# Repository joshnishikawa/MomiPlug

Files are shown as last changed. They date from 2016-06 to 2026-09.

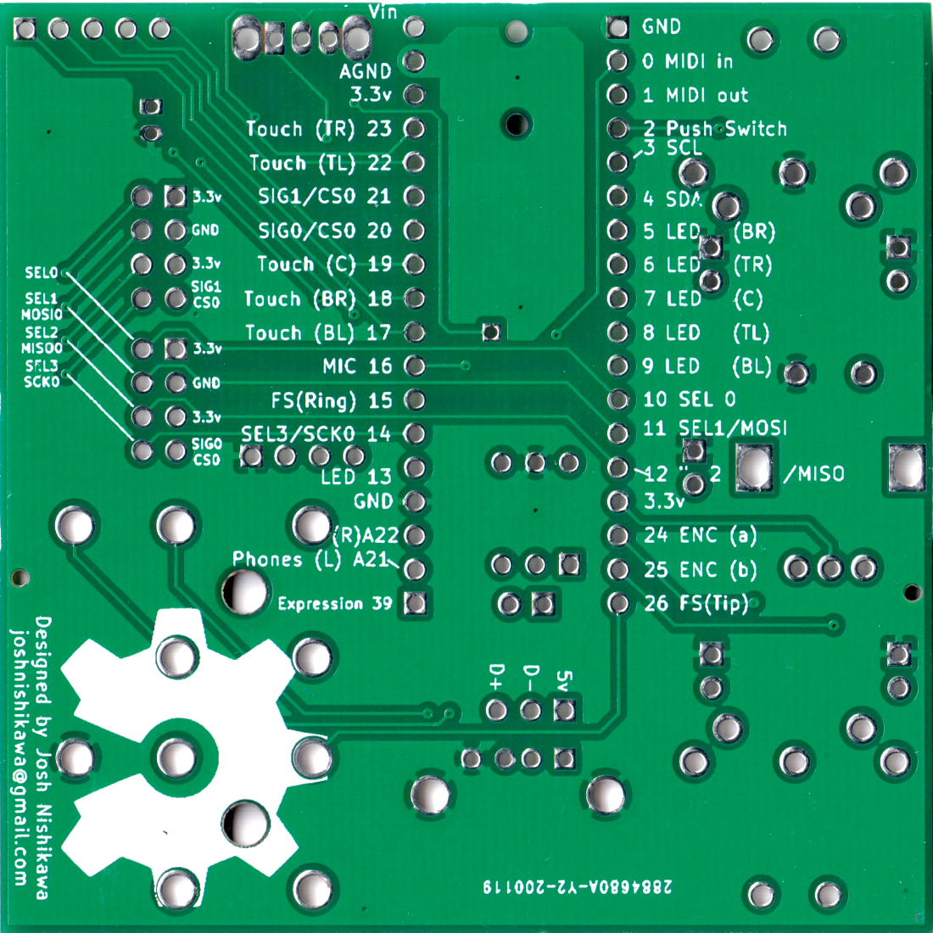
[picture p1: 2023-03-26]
MOMI3_silkscreen.jpg

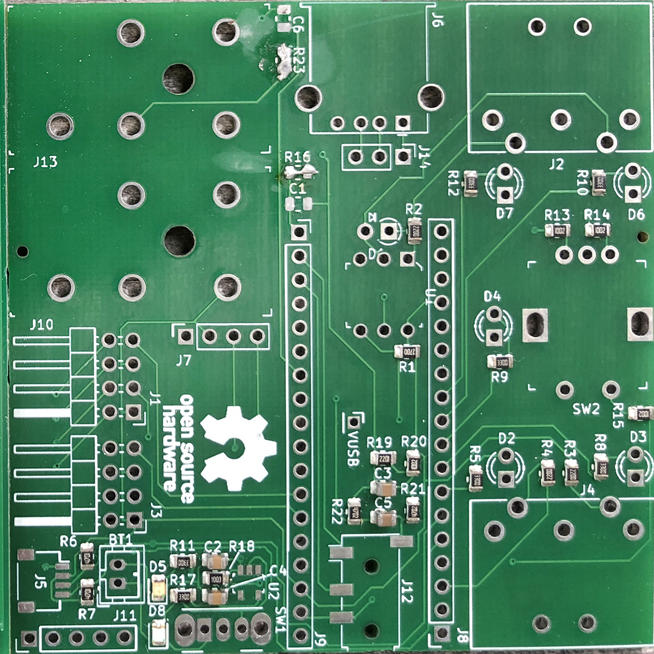
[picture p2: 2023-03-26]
MOMI3_surface.jpg

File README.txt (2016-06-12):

TEENSY 3.1 PIN ASSIGNMENTS
             ______
        ____|      |____
  GND -|-GND|      | 5V |- VBUS on USB host module
 MIDI -| 0  |______AGND-|- AGND (sleve and Mux16 GND)
 FS 1 -| 1        _3.3v-|- Voltage
SEL_A  |-2   AREF(_) 23 |- 1/4" analog return (ring)
SEL_B  |-3    A-1(_) 22-|  SER (display)
SEL_C  |-4    A-2(_) 21-|  Encoder Pin B
SEL_D  |-5           20-|  Encoder Pin A
 FS 0  |-6           19-| 'Edit' Button
 SRCK -| 7           18 |- Button 4
 RCLK -| 8           17 |- Button 3
  INT -| 9           16 |- Button 2
   SS  |-10          15 |- Button 1
 MOSI  |-11          14 |- Button 0
 MISO  |-12          13 |- SCK
       |________________|

  * '-' indicates which direction the wires run.

74HC595 (x2) PIN ASSIGNMENTS
             __ __
 Butn4 LED -| (_) |- 5V
 Butn3 LED -|     |- Butn5 LED
 Butn2 LED -|     |- SER from Teensy
 G Segment -|     |-
 F Segment -|  #1 |- RCLK
 E Segment -|     |- SRCK
 D Segment -|     |- 5V
       GND -|_____|- SER to #2
             __ __
 B Segment -| (_) |- 5V
 A Segment -|     |- C Segment
DP Segment -|     |- SER from #1
 Cathode 1 -|     |-
 Cathode 2 -|  #2 |- RCLK
 Cathode 3 -|     |- SRCK
 Butn1 LED -|     |- 5V
       GND -|_____|-

 * The 7 segments are split between
   the 2 chips so that a maximum of
   5 pins are HIGH at any given time.

7-SEGMENT LED PIN ASSIGNMENTS

      G  F  DP A  B
 _____|__|__|__|__|_
|O ___ O ___ O ___  |
| |   | |   | |   | |
| |___| |___| |___| |
| |   | |   | |   | |
| |___| |___| |___| |
|___________________|
   |  |  |  |  |  |
   E  1  2  C  D  3

 *It's wired up-side down so
  ignore the datasheet.

USB HOST MODULE PIN ASSIGNMENTS (from circuits@home)
          __________
         |          |
         |          |
       __|          |__
      |  |          |  |
      |  |__________|  |
      | _    5V -(_) _ |- (Be sure to break the VBUS jumper.)
  SS -|(_)          (_)|
MOSI -|(_)          (_)|
MISO -|(_)          (_)|
 SCK -|(_)          (_)|
      |(_)          (_)|
      |(_)          (_)|
      |(_)          (_)|
      |(_)          (_)|
3.3V -|(_)          (_)|- GND
      |(_)          (_)|- 3.3V
 GND -|(_)          (_)|
      |(_)          (_)|
      |________________|

5-PIN MIDI IN DIN PIN ASSIGNMENTS
_______________________
                       \
________________________\
      _____________      |
     /_____________\     |     ______________
    //      _2     \\    |    /     2    \   \__
   // 4_   (_)   _5 \\   |   / 5   0===  4\   \ \___
  ||  (_)       (_)  ||  |  |  0===     0==|        \
  ||  _           _  ||  |  |              |         |__
  || (_)         (_) ||  |  | 0===       0=|         |_ \
  || 1             3 ||  |  | 3          1 |         | \ \
  ||                 ||  |  |              |     ___/   \ \
   \\       _       //   |   \      _     /   /_/       / /
    \\_____| |_____//    |    \____| |___/___/         / /
     \-------------/     |                            / / 
_________________________|                            \ \

Pin 1 - Not Connected
Pin 2 - Not Connected
Pin 3 - Not Connected
Pin 4 - Through a 220 Ohm resistor and into 6N138 Pin 2
Pin 5 - From 6N138 Pin 3 

 * A diode and 270 Ohm resistor are also needed.
   See schematic below.

MIDI IN SCHEMATIC (6N138)        3.3V
                                  |
                           __ __  |   270 Ohm
            220 Ohm      -|1(_)8|~'~~~\/\/\/\_
DIN Pin 4~~~\/\/\/\~~~_~~~|2   7|-            |
DIN Pin 5~~~~~~~~~~~~~^~~~|3   6|~~~~~~~~~~~~~'~~~MIDI
                      D  -|4___5|~~GND          (Teensy)
                      i
                      o
                      d
                      e

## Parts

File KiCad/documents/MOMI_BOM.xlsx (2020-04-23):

Comment | Designator | Footprint | LCSC Part #（optional）
10uF | C1,C3,C5,C6 | C_0805_2012Metric
1uF | C2,C4 | C_0805_2012Metric
Green LED | D5 | LED_0805_2012Metric
Red LED | D8 | LED_0805_2012Metric
270 | R1 | R_0805_2012Metric
220 | R2,R3,R4 | R_0805_2012Metric
330 | R5,R8,R9,R10,R12,R11,R17 | R_0805_2012Metric
4.7k | R6,R7 | R_0805_2012Metric
10k | R13,R14,R15,R20 | R_0805_2012Metric
47k | R16,R21,R22,R23 | R_0805_2012Metric
2.2k | R19 | R_0805_2012Metric
100k | R18 | R_0805_2012Metric

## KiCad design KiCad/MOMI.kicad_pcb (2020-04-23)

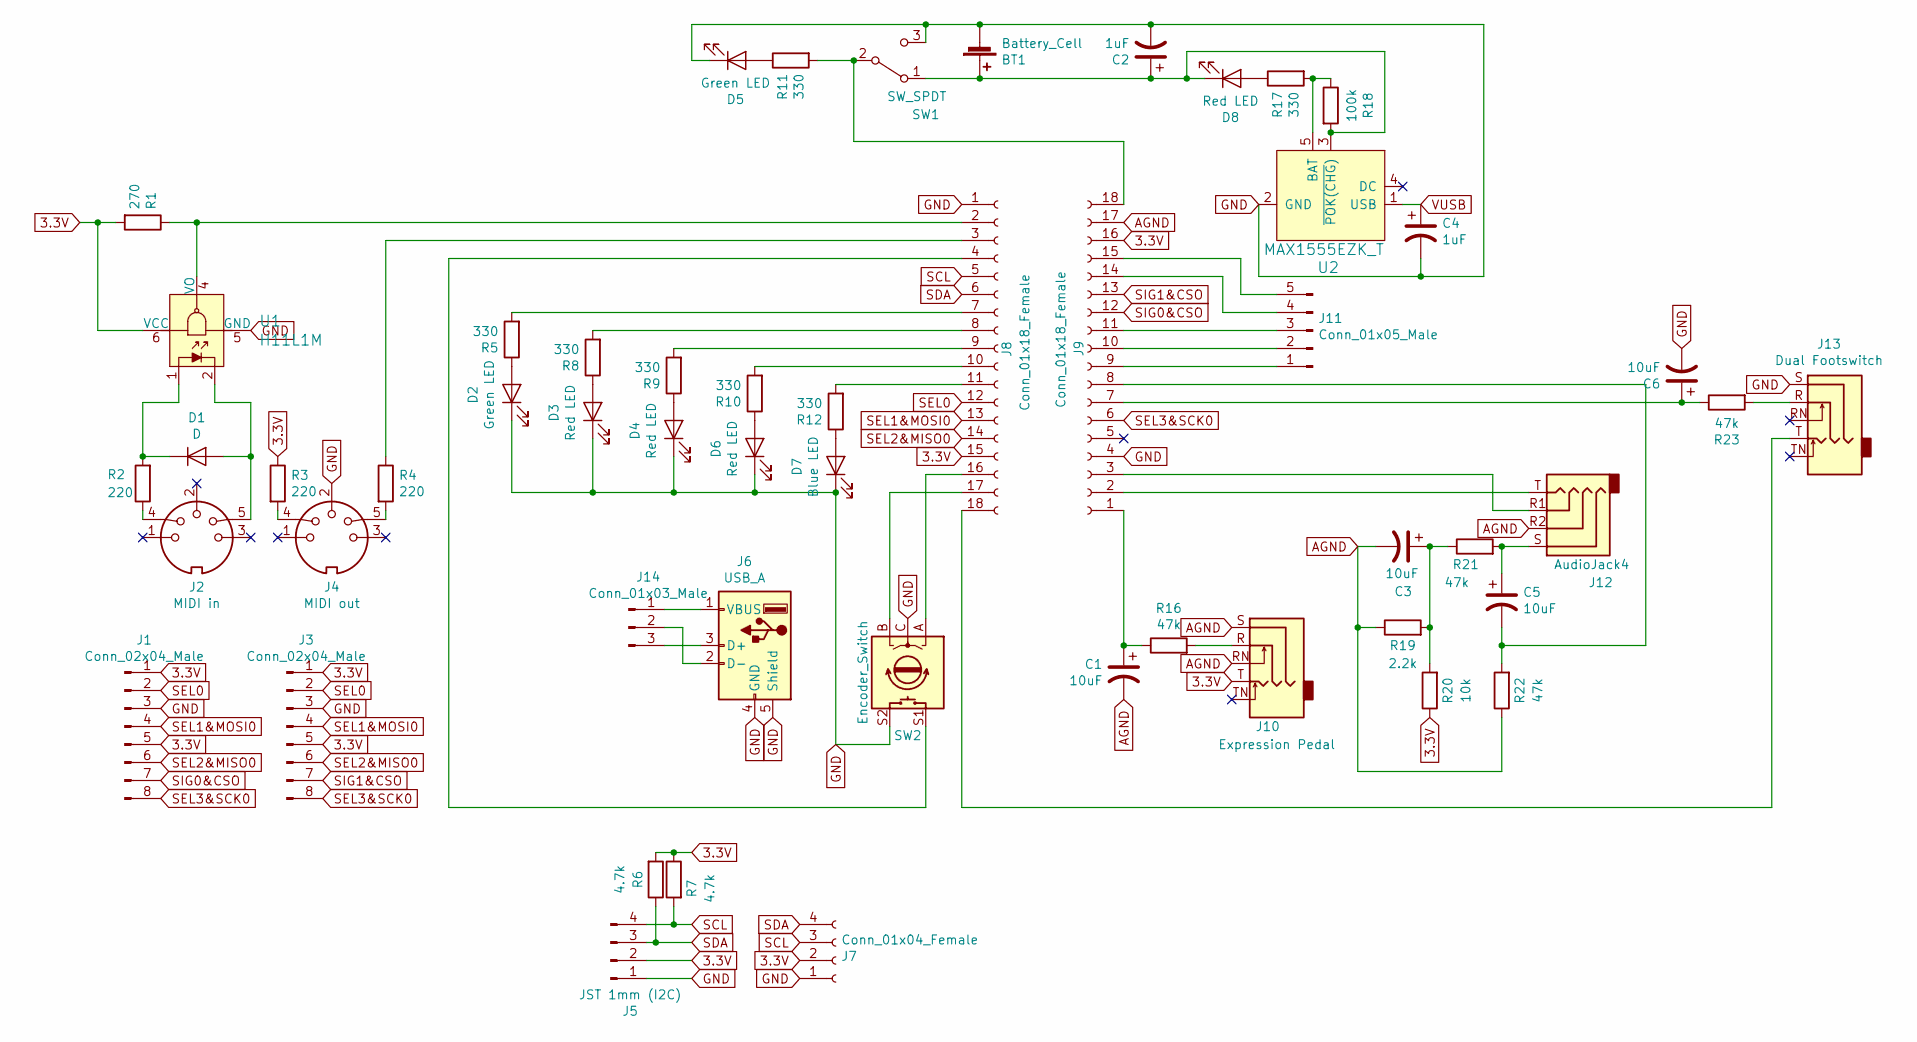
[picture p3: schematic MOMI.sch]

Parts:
BT1: Battery_Cell; JST_PH_B2B-PH-K_1x02_P2.00mm_Vertical
C1, C3, C5, C6: 10uF; C_0805_2012Metric
C2, C4: 1uF; C_0805_2012Metric
D1: D; D_A-405_P2.54mm_Vertical_AnodeUp
D2: Green LED; LED_D3.0mm
D3, D4, D6: Red LED; LED_D3.0mm
D5: Green LED; LED_0805_2012Metric
D7: Blue LED; LED_D3.0mm
D8: Red LED; LED_0805_2012Metric
J1, J3: Conn_02x04_Male; PinHeader_2x04_P2.54mm_Horizontal
J2: MIDI in; SDS-50J
J4: MIDI out; SDS-50J
J5: JST 1mm (I2C); JST_SH_SM04B-SRSS-TB_1x04-1MP_P1.00mm_Horizontal
J6: USB_A; USB_A_Stewart_SS-52100-001_Horizontal
J7: Conn_01x04_Female; PinSocket_1x04_P2.54mm_Vertical
J8, J9: Conn_01x18_Female; PinSocket_1x18_P2.54mm_Vertical
J10: Expression Pedal; Headphone_Jack_6.35mm_RA49B14B
J11: Conn_01x05_Male; PinHeader_1x05_P2.54mm_Vertical
J12: AudioJack4; Jack_3.5mm_PJ320D_Horizontal
J13: Dual Footswitch; Headphone_Jack_6.35mm_RA49B14B
J14: Conn_01x03_Male; Pin_Header_Straight_1x03_Pitch2.54mm
R1: 270; R_0805_2012Metric
R2, R3, R4: 220; R_0805_2012Metric
R5, R8, R9, R10, R11, R12, R17: 330; R_0805_2012Metric
R6, R7: 4.7k; R_0805_2012Metric
R16, R21, R22, R23: 47k; R_0805_2012Metric
R18: 100k; R_0805_2012Metric
R19: 2.2k; R_0805_2012Metric
R20: 10k; R_0805_2012Metric
SW1: SW_SPDT; SW_CuK_OS102011MA1QN1_SPDT_Angled
SW2: Encoder_Switch; Rotary_Encoder_Switched_PEC11R
U1: H11L1M; DIP-6_W7.62mm; MPN H11L1M; Digi-Key_PN H11L1-MQT-ND
U2: MAX1555EZK_T; SOT-753; MPN MAX1555EZK+T; Digi-Key_PN MAX1555EZK+TCT-ND

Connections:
3.3V: J1.1, J1.5, J3.1, J3.5, J5.2, J7.2, J8.15, J9.16, J10.T, R1.2, R3.1, R6.2, R7.1, R20.1, U1.6 (VCC)
AGND: C1.2, C3.2, J9.17, J10.RN, J10.S, J12.R2, R19.1, R22.1
GND: BT1.2 (-), C2.2, C4.2, C6.2, D2.1 (K), D3.1 (K), D4.1 (K), D5.1 (K), D6.1 (K), D7.1 (K), J1.3, J3.3, J4.2, J5.1, J6.4 (GND), J6.5 (Shield), J7.1, J8.1, J9.4, J13.S, SW1.3 (C), SW2.C, SW2.S2, U1.5 (GND), U2.2 (GND)
unnamed: BT1.1 (+), C2.1, D8.1 (K), R18.2, SW1.1 (A), U2.3 (~POK(CHG))
unnamed: C1.1, J9.1, R16.1
unnamed: C3.1, R19.2, R20.2, R21.1
unnamed: C5.1, J12.S, R21.2
unnamed: C5.2, J9.8, R22.2
unnamed: C6.1, J9.7, R23.1
unnamed: D1.1 (K), R2.2, U1.1
unnamed: D1.2 (A), J2.5, U1.2
unnamed: D2.2 (A), R5.1
unnamed: D3.2 (A), R8.1
unnamed: D4.2 (A), R9.1
unnamed: D5.2 (A), R11.1
unnamed: D6.2 (A), R10.1
unnamed: D7.2 (A), R12.1
unnamed: D8.2 (A), R17.1
unnamed: J2.4, R2.1
unnamed: J4.4, R3.2
unnamed: J4.5, R4.2
unnamed: J8.2, R1.1, U1.4 (VO)
unnamed: J8.3, R4.1
unnamed: J8.4, SW2.S1
unnamed: J8.7, R5.2
unnamed: J8.8, R8.2
unnamed: J8.9, R9.2
unnamed: J8.10, R10.2
unnamed: J8.11, R12.2
unnamed: J8.16, SW2.A
unnamed: J8.17, SW2.B
unnamed: J9.18, R11.2, SW1.2 (B)
unnamed: J10.R, R16.2
unnamed: J9.9, J11.1
unnamed: J9.10, J11.2
unnamed: J9.11, J11.3
unnamed: J9.14, J11.4
unnamed: J9.15, J11.5
unnamed: J9.3, J12.R1
unnamed: J9.2, J12.T
unnamed: J13.R, R23.2
unnamed: J8.18, J13.T
unnamed: J6.1 (VBUS), J14.1
unnamed: J6.2 (D-), J14.2
unnamed: J6.3 (D+), J14.3
unnamed: R17.2, R18.1, U2.5 (BAT)
SCL: J5.4, J7.3, J8.5, R7.2
SDA: J5.3, J7.4, J8.6, R6.1
SEL0: J1.2, J3.2, J8.12
SEL1&MOSI0: J1.4, J3.4, J8.13
SEL2&MISO0: J1.6, J3.6, J8.14
SEL3&SCK0: J1.8, J3.8, J9.6
SIG0&CSO: J1.7, J9.12
SIG1&CSO: J3.7, J9.13
VUSB: C4.1, U2.1 (USB)

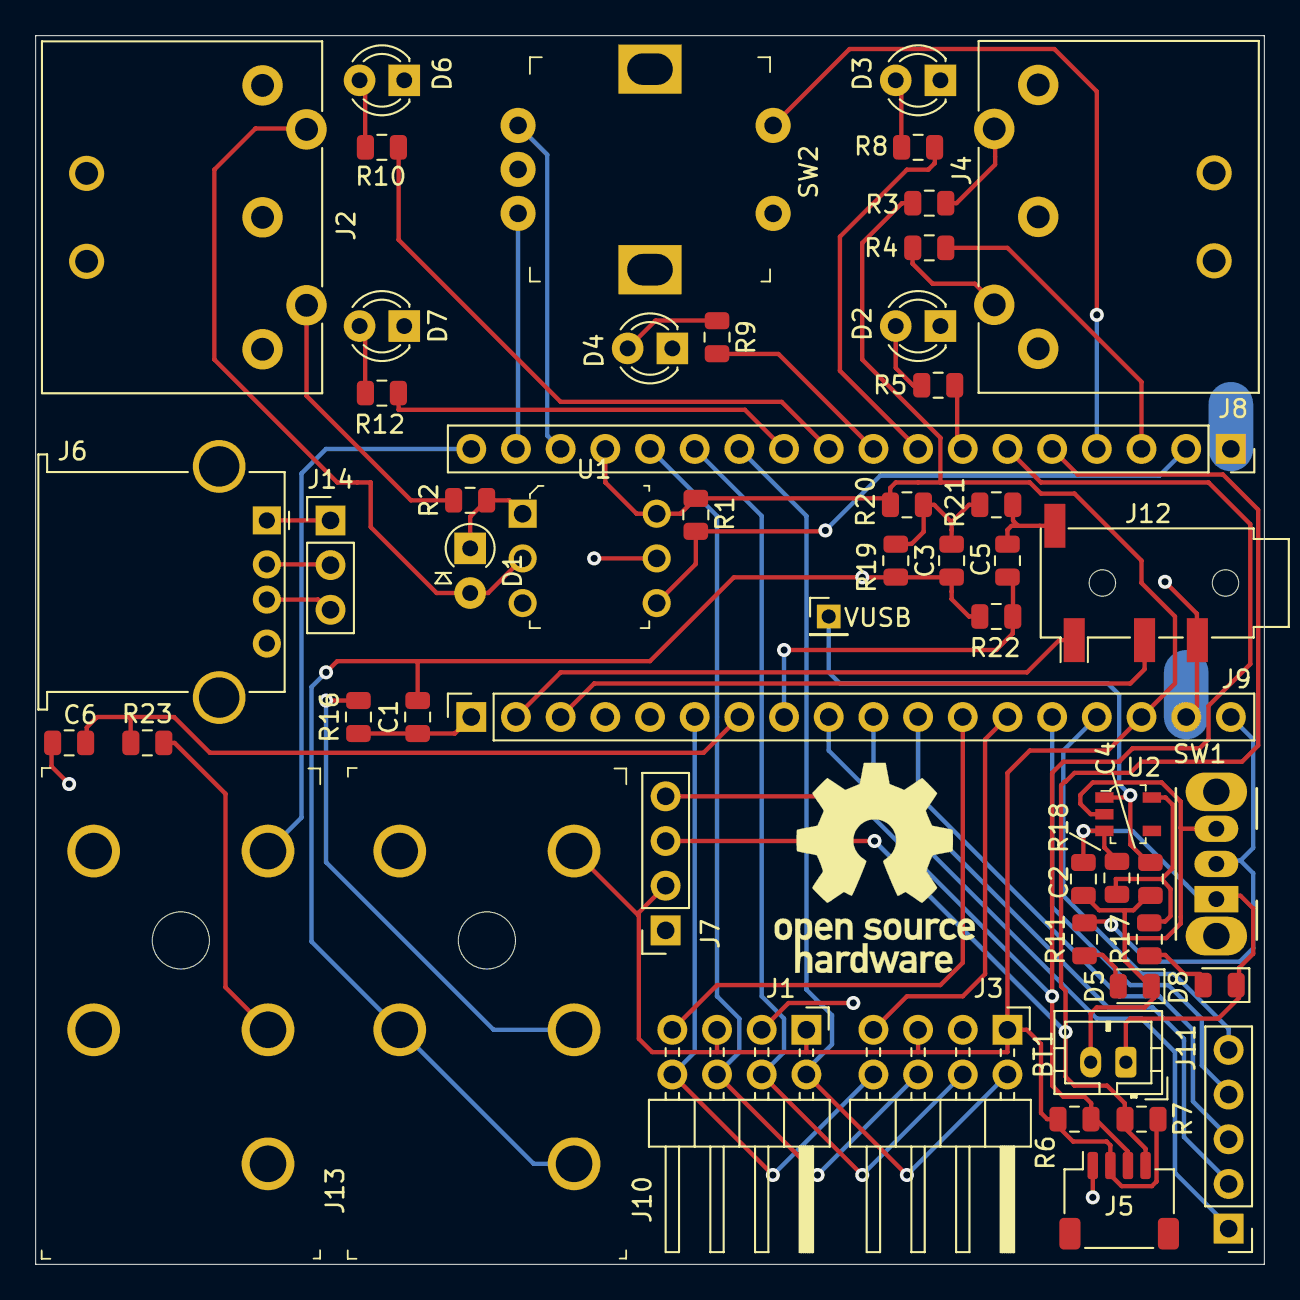
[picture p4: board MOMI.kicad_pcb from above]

Board: 2 copper layers, 69.8 x 69.8 mm, 53 parts (0 on the bottom side), 55 nets.

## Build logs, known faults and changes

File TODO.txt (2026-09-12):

MOMI should start in CONTROL mode.

If any of the touch, footswitch or MIDIpot inputs is triggered while the EDIT button is being held, 
the EDIT button may be released and we remain in CONFIG mode to allow the encoder to set values for the last item triggered.
When the EDIT button is pressed and released again, these values are set and we return to the previously
selected mode (TRACK or CONTROL).

If the Bottom Right touch input is selected (pin 17), all reads on pins 20 and 21 are halted.
THIS IS TOP PRIORITY! WE MUST BE ABLE TO STOP MUXES FROM BEING READ!
The current read state of the MUX pins is displayed on the 7-segment display. The EDIT button
may be released and the encoder may be used to scroll through these options.
  '----' Both MUX pins will be ignored.
  'A---' Pin 20 will read a single MIDIpot.
  'A--A' Pins 20 and 21 will each read a single MIDIpot.
  '8---' Pin 20 will read MUX8.
  '8--A' Pin 20 will read MUX8 and pin 21 swill read a single MIDIpot.
  '8--8' Pins 20 and 21 will each read a MUX8.
  'SPI-' Use SPI only - MOSI on pin 11, MISO on pin 12, CS on pin 20 and SCK on pin 14 ( use SPI.setSCK(14) )
  'SPIA' Use SPI on pin 20 and a single MIDIpot on pin 21.

If the Top Right input is selected (pin 23), the current octave setting is display on the 7-segment display.
The EDIT button may be released and the encoder may be used to scroll through these options. 
  'ocL-' Each note will be accompanied by a second note an octave lower.
  'oc-H' Each note will be accompanied by a second note an octave higher.
  'ocLH' Each note will be accompanied by two additional notes, one an octave higher and one an octave lower.
  'oc--' Only the note played will be sent.

If the Top Left input is selected (pin 19), the current transpose setting is displayed on the 7-segment display.
The EDIT button may be released and the encoder may be used to scroll down to -12 or up to 12 for note transposition.

If the Bottom Left input is elected (pin 18), the current expression state is displayed on the 7-segment display.
The EDIT button may be released and the encoder may be used to scroll through these options.
  'CAOS' Currently incorrectly implemented (check the 'MOMI3 init' commit).
  'ECHO' A digital delay where, the higher the reading, the more repeats and longer decay time.
  'both' Both CAOS and ECHO are used
  '----' Neither are used.

If the Center input is selected (pin 22), toggles whether MIDI FX apply to usb host too (wet, dry).

If any MIDIpot input is triggered while the EDIT button is held down,
the cut / -cut functionality should be the same but turning the encoder should change the CC number.
When EDIT is released 'SEnS' should be displayed on the 7-segment and, if the analog read changes
by more than 100, we need to keep track of inHi and inLo (displaying the analog value on th 7-segment). 
When the EDIT button is pressed and released again, inHi should be set to the 
highest reading -10 and inLo should be set to the lowest reading +10.

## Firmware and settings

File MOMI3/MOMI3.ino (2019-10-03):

#include "MOMIPLUG.h"

MIDI_CREATE_DEFAULT_INSTANCE();
MIDI_CREATE_INSTANCE(HardwareSerial, Serial1, MIDI1);
MIDI_CREATE_INSTANCE(HardwareSerial, Serial1, MIDI2);
MIDI_CREATE_INSTANCE(HardwareSerial, Serial1, MIDI3);
USBHost teensyUSBHost;
USBHub hub1(teensyUSBHost);
USBHub hub2(teensyUSBHost);
MIDIDevice USBMIDI(teensyUSBHost);

// PIN ASSIGNMENTS ##################################################
//MIDI in  is pin 0 by default
//MIDI out is pin 1 by default
const int enableFS = 2; //enable footswitches
const int enableEXP = 3;//enable expression pedal
const int sel_a = 4;    //selectors for analog and digital mux inputs
const int sel_b = 55;   //55 because pin 5 got fried. Oops!
const int sel_c = 6;    //
const int sel_d = 7;    //
const int led3 = 8;     //LED on center right
const int fs1led = 9;   //LED for FS1
const int led2 = 10;    //LED on upper right
const int fs0led = 11;  //LED for FS0
const int editPin = 12; //edit button (push switch on encoder)
const int led0 = 13;    //the onboard (orange) LED
const int expPin = 14;  //analog input for expression pedal
const int ringPin = 15; //footswitch 1
const int tipPin = 16;  //footswitch 0
const int but1pin = 17; //onboard buttons
const int but2pin = 18; //
const int but3pin = 19; //
const int muxPin1 = 20; //muxed analog input
const int audioVol = 21;//volume for 3.5mm jack
const int cap0pin = 22; //onboard Capacitive touch sensor
const int muxPin0 = 23; //muxed digital input
const int encPinA = 24; //pin A of encoder
const int encPinB = 25; //pin B of encoder
const int led1 = 26;    //LED on upper left

const int segG = 27;    //Pin 7
const int segD = 28;    //Pin 8
const int segF = 29;    //Pin 9
const int digit2 = 30;  //Pin 10
const int segB = 31;    //Pin 11
const int segA = 32;    //Pin 12
const int digit1 = 33;  //Pin 1
const int segE = 34;    //Pin 2
const int segC = 35;    //Pin 3
const int digit3 = 36;  //Pin 4
const int segDP= 37;    //Pin 5
const int digit4 = 38;  //Pin 6

const int analog = 39;  //2-pin female header for variable resistors
const int audioR = A21; //right headphone
const int audioL = A22; //left headphone

// DECLARATOINS #########################################################
byte MIDIchannel = 3;
bool readMIDIthru = true;
bool readAnalogMUX = false;
bool readDigitalMUX = false;
bool trackMode = false;
SevSeg DSP;
char DSPstring[5] = "    ";
int DP = 0;
Editor editor = Editor(encPinA, encPinB, editPin);
Track* Ts[3];
MIDIbutton* Bs[23];
MIDIpot* Ps[18];

// INITIALIZATION #######################################################
void setup(){
  Serial.begin(115200); //is this really necessary?
  delay(1500);
  MIDIchannel = EEPROM.read(0);
  readMIDIthru = EEPROM.read(1);
  readAnalogMUX = EEPROM.read(2);
  readDigitalMUX = EEPROM.read(3);
  DSP.Begin(COMMON_CATHODE, 4, digit1, digit2, digit3, digit4,
                               segA, segB, segC, segD, segE, segF, segG, segDP);
  DSP.SetBrightness(100); //Set the display to 100% brightness level
  
  Ts[0] = new Track(but1pin, 105, 2100);
  Ts[1] = new Track(but2pin, 106, 2100);
  Ts[2] = new Track(but3pin, 107, 2100);

  Bs[0] = new MIDIbutton(but1pin,  102, 1, 2100);
  Bs[1] = new MIDIbutton(but2pin,  103, 1, 2100);
  Bs[2] = new MIDIbutton(but3pin,  104, 1, 2100);
  Bs[3] = new MIDIbutton(ringPin,  80, EEPROM.read(4));
  Bs[4] = new MIDIbutton(tipPin,  81, EEPROM.read(8));
  Bs[5] = new MIDIbutton(ringPin, 107, 0);
  Bs[6] = new MIDIbutton(tipPin, 107, 0); //DELETE ME MAYBE???
  for(int i=7; i<23; i++){Bs[i] = new MIDIbutton(muxPin0,9+i, 1);} // CC 16~31

  Ps[0] = new MIDIpot(expPin, 85, EEPROM.read(12));
  Ps[0]->inputRange(8, 1015); // just cuz my expression pedal ain't great 
  Ps[1] = new MIDIpot(analog, 14);
  EEPROM.get(16, Ps[1]->inLo);
  EEPROM.get(20, Ps[1]->inHi);
  EEPROM.get(24, editor.touchLo);
  EEPROM.get(28, editor.touchHi);
  for(int i=2; i<18; i++){Ps[i] = new MIDIpot(muxPin1,14+i);} // CC 16~31

  pinMode(sel_a, OUTPUT);             //analog and digital mux selector 1
  pinMode(sel_b, OUTPUT);             //analog and digital mux selector 2
  pinMode(sel_c, OUTPUT);             //analog and digital mux selector 3
  pinMode(sel_d, OUTPUT);             //analog and digital mux selector 4
  pinMode(enableFS, INPUT_PULLUP);
  pinMode(enableEXP, INPUT_PULLUP);
  pinMode(fs0led, OUTPUT);
  pinMode(fs1led, OUTPUT);
  pinMode(led0, OUTPUT);
  pinMode(led1, OUTPUT);
  pinMode(led2, OUTPUT);
  pinMode(led3, OUTPUT);

  MIDI1.begin(MIDI_CHANNEL_OMNI); //MIDI1 MIDI2 and MIDI3 only need to send
  MIDI2.begin(MIDI_CHANNEL_OMNI); //no need to read each one
  MIDI3.begin(MIDI_CHANNEL_OMNI); //or set handlers for incoming messages

  MIDI.begin(MIDI_CHANNEL_OMNI);
  MIDI.setHandleNoteOff(onNoteOff);
  MIDI.setHandleNoteOn(onNoteOn);
  MIDI.setHandleAfterTouchPoly(onPolyPressure);
  MIDI.setHandleControlChange(onControl);
  MIDI.setHandleProgramChange(onProgram);
  MIDI.setHandleAfterTouchChannel(onAfterTouch);
  MIDI.setHandlePitchBend(onPitchBend);

  teensyUSBHost.begin();
  USBMIDI.setHandleNoteOff(onUSBNoteOff);
  USBMIDI.setHandleNoteOn(onUSBNoteOn);
  USBMIDI.setHandleAfterTouchPoly(onUSBPolyPressure);
  USBMIDI.setHandleControlChange(onUSBControl);
  USBMIDI.setHandleProgramChange(onUSBProgram);
  USBMIDI.setHandleAfterTouchChannel(onUSBAfterTouch);
  USBMIDI.setHandlePitchChange(onUSBPitchBend);

  // UNCOMMENT THESE TO RESTORE DEFAULTS
  /*EEPROM.put(0, 3); EEPROM.put(1, true);
  EEPROM.put(2, false); EEPROM.put(3, false);
  EEPROM.put(4, 0); EEPROM.put(8, 1);
  EEPROM.put(12, 0); EEPROM.put(16, 0); EEPROM.put(20, 1023);*/
}

// PROGRAM ##############################################################
void loop(){
  editor.bounce->update();

  // On Button Release ##################################################
  if (editor.bounce->risingEdge()){
    strcpy(DSPstring, "    ");
    editor.encoder->write(0);
    if (editor.editing == true){
      if(editor.target == 0){EEPROM.put(0, MIDIchannel);}
      else if(editor.target == 1){EEPROM.put(1, readMIDIthru);}
      else if(editor.target == 2){EEPROM.put(2, readAnalogMUX);}
      else if(editor.target == 3){EEPROM.put(3, readDigitalMUX);}
      else if(editor.target == 4){EEPROM.put(4, Bs[3]->mode);}
      else if(editor.target == 8){EEPROM.put(8, Bs[4]->mode);}
      else if(editor.target == 12){EEPROM.put(12, Ps[0]->mode);}
      else if(editor.target == 16){
        Ps[1]->inLo = editor.newInLo;
        Ps[1]->inHi = editor.newInHi;
        EEPROM.put(16, Ps[1]->inLo);
        EEPROM.put(20, Ps[1]->inHi);
      }
      else if(editor.target == 24){
        EEPROM.put(24, editor.touchLo);
        EEPROM.put(28, editor.touchHi);
      }
      editor.editing = false;
    }
    else{
      trackMode = !trackMode;
      if(trackMode){strcpy(DSPstring, "trac");}
      else{strcpy(DSPstring, "ctrl");}
    }
  }

  // On Button Press ####################################################
  else if (editor.bounce->fallingEdge()){ //calibrate the analog header
    editor.newInLo = analogRead(analog);
    editor.newInHi = editor.newInLo;
    editor.touchLo = touchRead(cap0pin);
    editor.touchHi = editor.touchLo;
    sprintf(DSPstring, "%4d", MIDIchannel);
  }

  // On Hold ############################################################
  // TODO: 'editing' and 'target' could be reduced to 1 variable inside the sketch
  else if (editor.bounce->read() == LOW){
    int newChannel = editor.editChannel();
    if (newChannel != MIDIchannel){
      editor.editing = true;
      editor.target = 0;
      MIDIchannel = newChannel;
      sprintf(DSPstring, "%4d", MIDIchannel);
    }
    if (Bs[0]->read() == 127){
      editor.editing = true;
      editor.target = 1;
      readMIDIthru = !readMIDIthru;
    }
    if (Bs[1]->read() == 127){
      editor.editing = true;
      editor.target = 2;
      readAnalogMUX = !readAnalogMUX;
    }
    if (Bs[2]->read() == 127){
      editor.editing = true;
      editor.target = 3;
      readDigitalMUX = !readDigitalMUX;
    }
    if (digitalRead(enableFS)){ // TODO: use delay to prevent MIDI when hot-plugging
      if (Bs[3]->read() == 127){
        editor.editing = true;
        editor.target = 4;
        Bs[3]->mode = Bs[3]->mode == 1 ? 0 : 1;
        if(Bs[3]->mode == 1){strcpy(DSPstring, "lach");}
        else{strcpy(DSPstring, "hold");}
      }
      if (Bs[4]->read() == 127){
        editor.editing = true;
        editor.target = 8;
        Bs[4]->mode = Bs[4]->mode == 1 ? 0 : 1;
        if(Bs[4]->mode == 1){strcpy(DSPstring, "lach");}
        else{strcpy(DSPstring, "hold");}
      }
    }
    if (digitalRead(enableEXP) && Ps[0]->read() == 127){ // TODO: use delay to prevent MIDI when hot-plugging
      editor.editing = true;
      editor.target = 12;
      Ps[0]->mode = !Ps[0]->mode;
      if(Ps[0]->mode){strcpy(DSPstring, " cut");}
      else{strcpy(DSPstring, "-cut");}
    }
    
    if (editor.setAnalog(analog)){
      editor.editing = true;
      editor.target = 16;
      strcpy(DSPstring, "setH");
    }

    if (editor.setTouch(cap0pin)){
      editor.editing = true;
      editor.target = 24;
      strcpy(DSPstring, "setT");
    }

    digitalWrite(led1, readMIDIthru);
    digitalWrite(led2, readAnalogMUX);
    digitalWrite(led3, readDigitalMUX);
  }
  
  else{
  // In Track Mode Or Control Mode ######################################
    int newVal = 0;
    if (digitalRead(3) == HIGH){
      newVal = Ps[0]->send();              // Send MIDI for EXP Pedal
      if (newVal >= 0){
        sprintf(DSPstring, "%4d", newVal);      
        DSPstring[0] = 'E';
      }
    }
    newVal = Ps[1]->send();              // Send MIDI for Analog Header
    if (newVal >= 0){
      sprintf(DSPstring, "%4d", newVal);      
      DSPstring[0] = 'h';
    }

    if (readMIDIthru){
      teensyUSBHost.Task();
      USBMIDI.read();
      MIDI.read();
      digitalWrite(led0, chaos(cap0pin, editor.touchLo, editor.touchHi*.8, editor.touchHi, 24, 96) + 1);
      // adding 1 to the returned value of -1 makes 0 which turns the LED off, otherwise on
    }

    if (readAnalogMUX || readDigitalMUX){
    for(int i=0; i<8; i++){               // USE i<16 FOR MUX16
//        digitalWrite(sel_d, (i&15)>>3); // UNCOMMENT FOR MUX16
        digitalWrite(sel_c, (i&7)>>2);
        digitalWrite(sel_b, (i&3)>>1);
        digitalWrite(sel_a, (i&1));

        if (readAnalogMUX){
          newVal = Ps[i+2]->send();
          if (newVal >= 0){
            sprintf(DSPstring, "%4d", newVal);
            DSPstring[0] = 'A';
          }
        }
        if (readDigitalMUX){
          newVal = Bs[i+7]->send();
          if (newVal >= 0){
            sprintf(DSPstring, "%4d", newVal);
            DSPstring[0] = 'd';
          }
        }
      }
    }  
    // In Track Mode ######################################################
    if (trackMode){
      int incdec = editor.encoder->read();
      for(int i=0; i<3; i++){
        int newState = Ts[i]->send();
        if(newState >= 0){
          sprintf(DSPstring, "%4d", newState);
        }
        if (incdec){
          int newLevel = Ts[i]->vol(incdec);
          if(newLevel >= 0){
            sprintf(DSPstring, "%4d", newLevel);
          }
        }
      }
      if (incdec){editor.encoder->write(0);}
      bool recState = record(Bs[5]->read() == 127, Bs[6]->read() == 127);
      DP = 15;
      digitalWrite(fs0led, recState);
      digitalWrite(fs1led, !digitalRead(tipPin));
      digitalWrite(led1, Ts[0]->state);
      digitalWrite(led2, Ts[1]->state);
      digitalWrite(led3, Ts[2]->state);
    }

    // In Control Mode ####################################################
    else{
      newVal = editor.send();
      if(newVal >= 0){
        sprintf(DSPstring, "%4d", editor.level);
        DSPstring[0] = 'r';
      }
      for(int i=0;i<3;i++){                // Send MIDI for Onboard Buttons
        newVal = Bs[i]->send();
        if (newVal >= 0){
          sprintf(DSPstring, "%4d", newVal);
          DSPstring[0] = 'b';
        }
      }
      if (digitalRead(2) == HIGH){
        for(int i=3;i<5;i++){                // Send MIDI for Foot Switches
          newVal = Bs[i]->send();
          if (newVal >= 0){
            sprintf(DSPstring, "%4d", newVal);
            DSPstring[0] = 'f';
          }
        }
      }
      
      DP = 0;
      digitalWrite(led1, Bs[0]->state);
      digitalWrite(led2, Bs[1]->state);
      digitalWrite(led3, Bs[2]->state);
      digitalWrite(fs0led, Bs[3]->state);
      digitalWrite(fs1led, Bs[4]->state);
    }
  }
  DSP.DisplayString(DSPstring, DP); // Display most recently stored information
}

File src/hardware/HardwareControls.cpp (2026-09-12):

#include "HardwareControls.h"

HardwareControls hw;

HardwareControls::HardwareControls()
    : encoderButton(Pins::ENCODER_BUTTON, 50),
      encoder(Pins::ENCODER_A, Pins::ENCODER_B),
      encoderLevel(0),
      touchTopLeft(Pins::TOUCH_TOP_LEFT, MidiCC::TOUCH_TOP_LEFT, LATCH, TOUCH),
      touchCenter(Pins::TOUCH_CENTER, MidiCC::TOUCH_CENTER, LATCH, TOUCH),
      touchTopRight(Pins::TOUCH_TOP_RIGHT, MidiCC::TOUCH_TOP_RIGHT, LATCH, TOUCH),
      touchBottomRight(Pins::TOUCH_BOTTOM_RIGHT, MidiCC::TOUCH_BOTTOM_RIGHT, LATCH, TOUCH),
      footSwitch1(Pins::FOOTSWITCH_1, MidiCC::FOOTSWITCH_1, MOMENTARY),
      footSwitch0(Pins::FOOTSWITCH_0, MidiCC::FOOTSWITCH_0, LATCH),
      expressionPedal(Pins::EXPRESSION_PEDAL, MidiCC::EXPRESSION_PEDAL),
      mux0Pots{
          MIDIpot(Pins::MUX_ANALOG_IN_0, MidiCC::MUX0_POT_BASE + 0),
          MIDIpot(Pins::MUX_ANALOG_IN_0, MidiCC::MUX0_POT_BASE + 1),
          MIDIpot(Pins::MUX_ANALOG_IN_0, MidiCC::MUX0_POT_BASE + 2),
          MIDIpot(Pins::MUX_ANALOG_IN_0, MidiCC::MUX0_POT_BASE + 3),
          MIDIpot(Pins::MUX_ANALOG_IN_0, MidiCC::MUX0_POT_BASE + 4),
          MIDIpot(Pins::MUX_ANALOG_IN_0, MidiCC::MUX0_POT_BASE + 5),
          MIDIpot(Pins::MUX_ANALOG_IN_0, MidiCC::MUX0_POT_BASE + 6),
          MIDIpot(Pins::MUX_ANALOG_IN_0, MidiCC::MUX0_POT_BASE + 7)
      },
      mux1Pots{
          MIDIpot(Pins::MUX_ANALOG_IN_1, MidiCC::MUX1_POT_BASE + 0),
          MIDIpot(Pins::MUX_ANALOG_IN_1, MidiCC::MUX1_POT_BASE + 1),
          MIDIpot(Pins::MUX_ANALOG_IN_1, MidiCC::MUX1_POT_BASE + 2),
          MIDIpot(Pins::MUX_ANALOG_IN_1, MidiCC::MUX1_POT_BASE + 3),
          MIDIpot(Pins::MUX_ANALOG_IN_1, MidiCC::MUX1_POT_BASE + 4),
          MIDIpot(Pins::MUX_ANALOG_IN_1, MidiCC::MUX1_POT_BASE + 5),
          MIDIpot(Pins::MUX_ANALOG_IN_1, MidiCC::MUX1_POT_BASE + 6),
          MIDIpot(Pins::MUX_ANALOG_IN_1, MidiCC::MUX1_POT_BASE + 7)
      },
      haltMuxReads(true)
{
    touchButtons[0] = &touchTopLeft;
    touchButtons[1] = &touchCenter;
    touchButtons[2] = &touchTopRight;
    touchButtons[3] = &touchBottomRight;
}

void HardwareControls::begin() {
    pinMode(Pins::ENCODER_BUTTON, INPUT_PULLUP);

    // Use fixed thresholds - no dynamic baseline calibration
    touchTopLeft.setThreshold(TouchConfig::THRESHOLD_TOP_LEFT);
    touchCenter.setThreshold(TouchConfig::THRESHOLD_CENTER);
    touchTopRight.setThreshold(TouchConfig::THRESHOLD_TOP_RIGHT);
    touchBottomRight.setThreshold(TouchConfig::THRESHOLD_BOTTOM_RIGHT);

    expressionPedal.inputRange(ExpressionConfig::INPUT_MIN, ExpressionConfig::INPUT_MAX);

    haltMuxReads = (configMgr.getMuxMode() == MUX_NONE);
    if (haltMuxReads) {
        pinMode(Pins::MUX_ANALOG_IN_0, INPUT_PULLDOWN);
        pinMode(Pins::MUX_ANALOG_IN_1, INPUT_PULLDOWN);
    }

    initLeds();
}

void HardwareControls::initLeds() {
    pinMode(Pins::LED_TOP_LEFT, OUTPUT);
    pinMode(Pins::LED_CENTER, OUTPUT);
    pinMode(Pins::LED_TOP_RIGHT, OUTPUT);
    pinMode(Pins::LED_FOOTSWITCH_0, OUTPUT);
    pinMode(Pins::LED_FOOTSWITCH_1, OUTPUT);
    pinMode(Pins::LED_ONBOARD, OUTPUT);
}

void HardwareControls::initSpi() {
    pinMode(Pins::MUX_ANALOG_IN_0, OUTPUT); // Pin 20 as CS
    digitalWrite(Pins::MUX_ANALOG_IN_0, HIGH);
    SPI.setMOSI(Pins::MUX_SEL_B); // Pin 11
    SPI.setMISO(Pins::MUX_SEL_C); // Pin 12
    SPI.setSCK(Pins::MUX_SEL_D);  // Pin 14
    SPI.begin();
}

void HardwareControls::updateModesFromConfig(const MomiConfig& cfg) {
    footSwitch0.mode = cfg.fs0Mode;
    footSwitch1.mode = cfg.fs1Mode;
    expressionPedal.killSwitch = cfg.expKillSwitch;
    expressionPedal.number = cfg.expCcNumber;
    expressionPedal.inputRange(cfg.expInLo, cfg.expInHi);

    haltMuxReads = (cfg.muxMode == MUX_NONE);

    if (cfg.muxMode == MUX_NONE) {
        pinMode(Pins::MUX_ANALOG_IN_0, INPUT_PULLDOWN);
        pinMode(Pins::MUX_ANALOG_IN_1, INPUT_PULLDOWN);
    } else if (cfg.muxMode == MUX_SPI || cfg.muxMode == MUX_SPI_A) {
        initSpi();
    } else {
        pinMode(Pins::MUX_ANALOG_IN_0, INPUT);
        pinMode(Pins::MUX_ANALOG_IN_1, INPUT);
    }
}

int HardwareControls::sendEncoderMidi(uint8_t channel) {
    int incdec = encoder.read();
    if (incdec >= 4 && encoderLevel < 127) {
        encoderLevel += 1;
        encoder.write(0);
        usbMIDI.sendControlChange(MidiCC::ENCODER_PARAM, encoderLevel, channel);
        return encoderLevel;
    }
    else if (incdec <= -4 && encoderLevel > 0) {
        encoderLevel -= 1;
        encoder.write(0);
        usbMIDI.sendControlChange(MidiCC::ENCODER_PARAM, encoderLevel, channel);
        return encoderLevel;
    }
    else if (incdec >= 4 || incdec <= -4) {
        encoder.write(0);
        return -1;
    }
    return -1;
}

int HardwareControls::readEncoderStep() {
    int delta = encoder.read();
    if (delta >= 4) {
        encoder.write(0);
        return 1;
    } else if (delta <= -4) {
        encoder.write(0);
        return -1;
    }
    return 0;
}
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

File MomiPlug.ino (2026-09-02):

#include <Arduino.h>
#include <IntervalTimer.h>
#include "src/midi/MidiRouter.h"
#include "src/ui/AppStateMachine.h"

// 1 kHz hardware timer for 7-segment display multiplexing
IntervalTimer displayTimer;

void displayTimerISR() {
    display.refreshHardware();
}

void setup() {
    Serial.begin(9600);

    // Initialize MIDI Routing & USB Host
    midiRouter.begin();

    // Initialize Application Engine & Hardware Subsystems
    app.begin();

    // Start background display refresh interrupt (1000 microseconds period)
    displayTimer.begin(displayTimerISR, 1000);
}

void loop() {
    // Process incoming DIN MIDI & 4-port USB Host packets
    midiRouter.process();

    // Update state machine, hardware inputs, displays, and synthesis
    app.update();
}

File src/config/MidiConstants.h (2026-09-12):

#pragma once
#include <stdint.h>

namespace MidiCC {
    // Encoder Parameter Control
    constexpr uint8_t ENCODER_PARAM       = 3;

    // Track Mode Controls
    constexpr uint8_t TRACK_ARM_BASE      = 107; // CC 107 (Track 0), 108 (Track 1), 109 (Track 2)
    constexpr uint8_t TRACK_VOL_OFFSET    = 3;   // Track Vol = Arm CC + 3 -> CC 110, 111, 112
    constexpr uint8_t SCENE_RECORD_START  = 111; // Scenes cycle CC 111..119
    constexpr uint8_t SCENE_RECORD_END    = 119;
    constexpr uint8_t SCENE_STOP          = 111;

    // Hardware Touch Controls (Latching)
    constexpr uint8_t TOUCH_TOP_LEFT      = 102;
    constexpr uint8_t TOUCH_CENTER        = 103;
    constexpr uint8_t TOUCH_TOP_RIGHT     = 104;
    constexpr uint8_t TOUCH_BOTTOM_RIGHT  = 105;

    // Footswitches & Pedals
    constexpr uint8_t FOOTSWITCH_1        = 80;  // FS1 (Ring)
    constexpr uint8_t FOOTSWITCH_0        = 81;  // FS0 (Tip)
    constexpr uint8_t EXPRESSION_PEDAL    = 85;

    // Multiplexer Pots (8 per bank)
    constexpr uint8_t MUX0_POT_BASE       = 48;  // CC 48..55 (Bank A)
    constexpr uint8_t MUX1_POT_BASE       = 56;  // CC 56..63 (Bank B)

    // Standard MIDI Control Changes
    constexpr uint8_t SUSTAIN_PEDAL       = 64;
}

namespace UsbCable {
    // 0-indexed virtual cable numbers for usbMIDI.send*(..., cable)
    constexpr uint8_t DEFAULT_PORT        = 0; // Port 1
    constexpr uint8_t SYNTH_PORT          = 1; // Port 2
    constexpr uint8_t CHORD_PORT          = 2; // Port 3
    constexpr uint8_t ROUTE_PORT          = 3; // Port 4
}

namespace TouchConfig {
    // Capacitive touch activation thresholds (Fixed values - no dynamic calibration)
    constexpr int THRESHOLD_TOP_LEFT      = 1150;
    constexpr int THRESHOLD_CENTER        = 1150;
    constexpr int THRESHOLD_TOP_RIGHT     = 1150;
    constexpr int THRESHOLD_BOTTOM_RIGHT  = 1350; // Pin 17 baseline is higher; original was 1400/1450
    constexpr int THRESHOLD_BOTTOM_LEFT   = 1080; // Pin 18 (Chaos pad resting ~1000-1025, active 1080+)

    // Chaos Pad (Pin 18)
    constexpr uint16_t CHAOS_IN_LO        = 1010;
    constexpr uint16_t CHAOS_IN_HI        = 1150;
    constexpr uint8_t CHAOS_NOTE_MIN      = 48; // C3
    constexpr uint8_t CHAOS_NOTE_MAX      = 84; // C6
    constexpr uint8_t CHAOS_VELOCITY      = 96;
    constexpr uint8_t CHAOS_POLL_MS       = 10; // 20ms cadence
}

namespace ExpressionConfig {
    constexpr int INPUT_MIN               = 10;
    constexpr int INPUT_MAX               = 900;
    constexpr int KILLSWITCH_THRESHOLD    = 850;
}

namespace EchoConfig {
    // Touch range for Echo expression pad (Pin 18)
    constexpr uint16_t TOUCH_THRESHOLD    = 1020; // Pin 18 touch threshold (Chaos pad active 1010+)
    constexpr uint16_t TOUCH_FIRM         = 1150; // Firm touch level (maximum repeats & decay)
    constexpr uint8_t  MIN_REPEATS        = 1;    // Light touch gives 1 subtle repeat
    constexpr uint8_t  MAX_REPEATS        = 8;    // Firm touch gives 8 repeats ("several times")
    constexpr uint16_t MIN_DELAY_MS       = 130;  // Quick delay for light touch
    constexpr uint16_t MAX_DELAY_MS       = 380;  // Long delay for firm touch (over 3s decay)
}

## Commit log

2015-11-23 Made CC the default mode (not track)
2016-05-16 Preparing for Onboard Editing Capability
    The editor class now detects user triggered input and calls the
    appropriate function for the input type (although the function doesn't
    do anything yet). A new? 'track' class handles arm, record and volume
    for DAW tracks.
2016-05-23 now using EEPROM
    EEPROM now stores button, footswitch and track states, track and encoder
    levels. Changed some data types and sorted public and private variables.
    Buttons now display CC number when ON; 0 when OFF. Used longer bounce
    time. editChannel() only requires one argument. edit() still doesn't
    work.
2016-05-26 EDITOR MATERIALIZES!!!
    The Editor now changes numbers, min, max and modes for buttons or pots
    and saves values to EEPROM. Editor now acts as a MIDI encoder. Display
    supports more characters and now blinks a DP. Added more keywords.
2016-05-27 Pause MUX read
    New variable allows user to change their mind about which control to
    edit before the edit button is released.
2019-09-30 Everything works ;^)
    *Added option to calibrate Touch sensor.
    *MIDI out now works.
    *Use 2 MIDI out ports and 2 usbMIDI out ports.
    *sel_b changed to a pin that's not dead
    *Keep certain MIDI controllers active in "track" mode
2019-11-20 Various Improvements
    editor.target and editor.editme are now one variable (but should be a group of bools...later, eh?)
    Fixed a bug where the MIDI channel was being set to 255.
    Threshold for onboard buttons is auto-detected.
2019-11-24 New Features
    Added USBhost input to the chaos() function. Made chaos() more chaotic. Added a 2 second timer on the enable pins so you can safely hotplug (but not hot-unplug foot controllers). Now, in edit mode, any number of things can be edited simultaniously. Fixed a bug that only allowed readAnalogMUX to toggle once. Got bulk send working. Disabled the pot on the side because it interferes with the expression pedal (sigh).
2020-01-17 Added KiCad files
    [ACJS-MHDR.stp, AUDIO_JACK_3_5MM_TRRS_SMD_RA.STL, CUI_DEVICES_SDS-50J.step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]
2020-04-23 Add KiCad files
    [ACJS-MHDR.stp, AUDIO_JACK_3_5MM_TRRS_SMD_RA.STL, CUI_DEVICES_SDS-50J.step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]
2021-11-21 new pinout for circuit board
    [MOMI.sch]
2026-08-29 switch is the new button
